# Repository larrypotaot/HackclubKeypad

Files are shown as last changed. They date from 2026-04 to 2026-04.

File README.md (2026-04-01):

# 60% Keyboard Addon For Gaming and Other
* A roughly 3x6 layout for F row and arrow keys, alongside a rotary encoder for fun. It is hotswappable and contains LEDs for each key
* I made this to have a dedicated F row and arrow keys for my 60% keyboard since many games require them and don't work with FN shortcuts.
* Uses QMK software
* *I need a soldering iron please :D



# PCB



Schematic


Layout: https://www.keyboard-layout-editor.com/#/gists/ed5083c6de0b27ba4e196096e7faea45

#BOM
* Solder Iron
* 3.5mm standoffs
* EVA foam

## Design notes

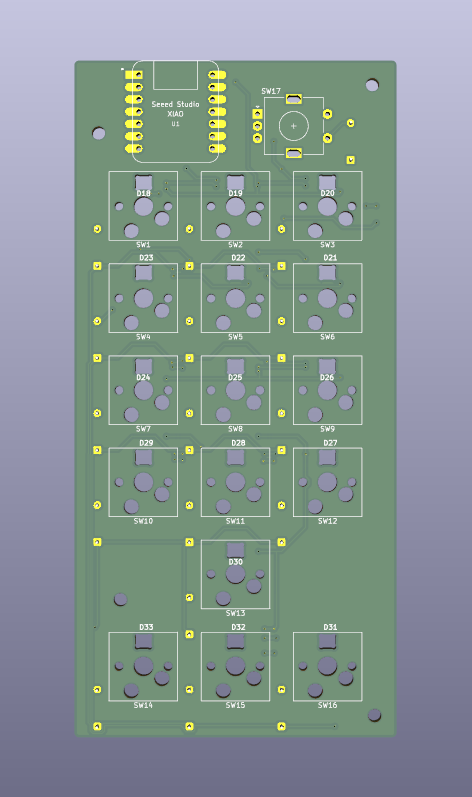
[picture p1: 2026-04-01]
images/PCBrender.png

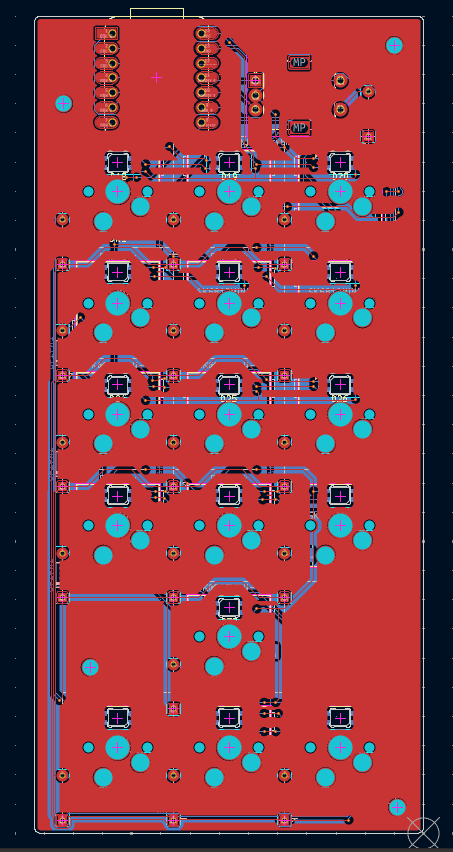
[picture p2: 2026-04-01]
images/PCBShematic.png

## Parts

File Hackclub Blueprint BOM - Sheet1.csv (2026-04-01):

Product Name | Product Link | Product Cost | Product Amount | Total Price
PCB from JCLPCB |  | $11.10 | 1 | $12.12
XIAO RP2040 MCU | https://www.aliexpress.us/item/3256808466485186.html?curPageLogUid=k8XzlSRWS6MQ | $4.87 | 1 | $12.81
EC11 Rotary Encoder | https://www.aliexpress.us/item/3256804721769785.html?curPageLogUid=tFcVPHu6YbhX | $3.33 | 1 | $2.18
Hotswap MX Socket | https://www.aliexpress.us/item/3256809607722645.html?curPageLogUid=7BINs2SNRA9A | $3.28 | 1 | $3.28
SK6812MINI-E LED | https://www.aliexpress.us/item/3256808122486614.html?curPageLogUid=gLfymRNrDhIw | $2.10 | 1 | $7.01
1N4148 Diodes |  | FREE |  | FREE
GATERON KS-3X1 V2 Milky Yellow Pro Switches | https://www.aliexpress.us/item/3256808499657735.html?curPageLogUid=gDV6XrdzS8fW | $12.19 | 1 | $12.19
Keycaps |  | FREE | 16 | FREE
M2.5 Screws and Nuts (8mm, 12mm, 16mm) |  | FREE |  | FREE

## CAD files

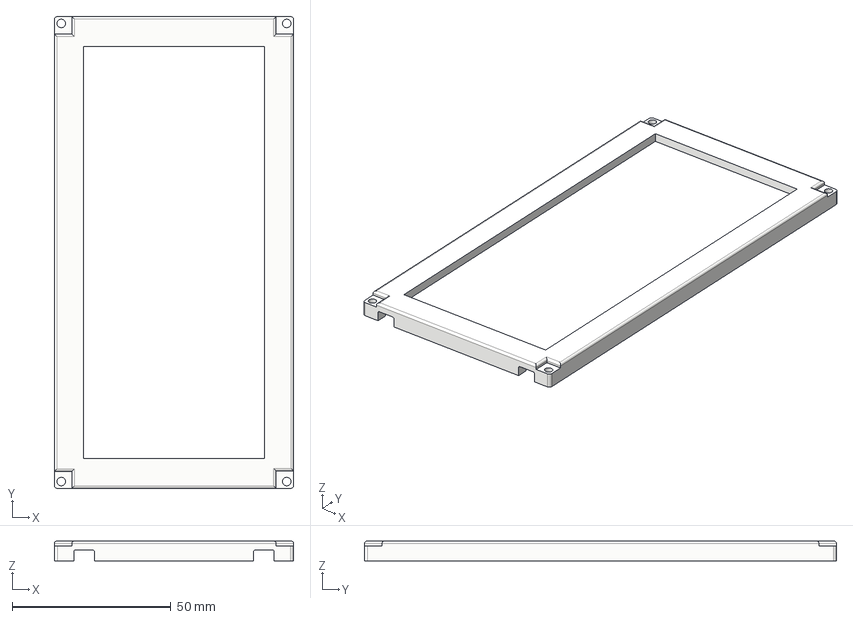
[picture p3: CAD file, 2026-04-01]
cad/TopCase.step
75.4 x 148.8 x 6.29 mm

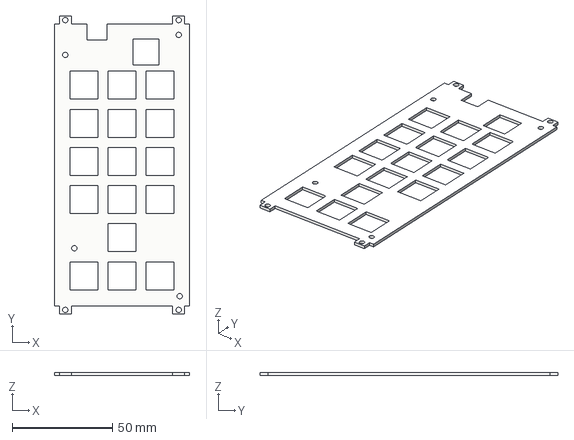
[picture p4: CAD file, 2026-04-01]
cad/Plate.step
67.5 x 148.8 x 1.50 mm

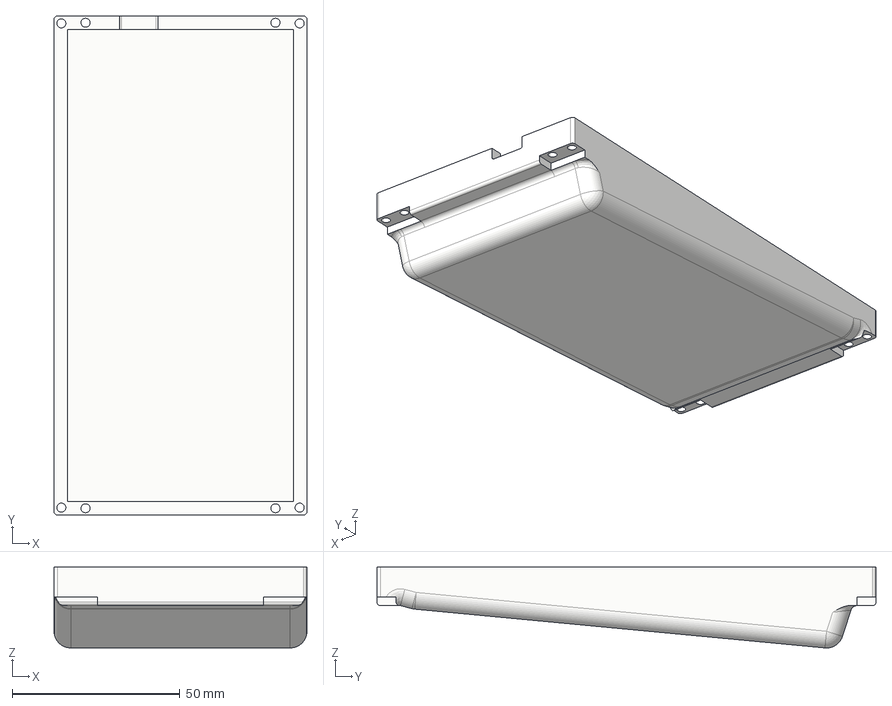
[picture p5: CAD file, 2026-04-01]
cad/BottomCase.step
75.5 x 148.8 x 24.1 mm

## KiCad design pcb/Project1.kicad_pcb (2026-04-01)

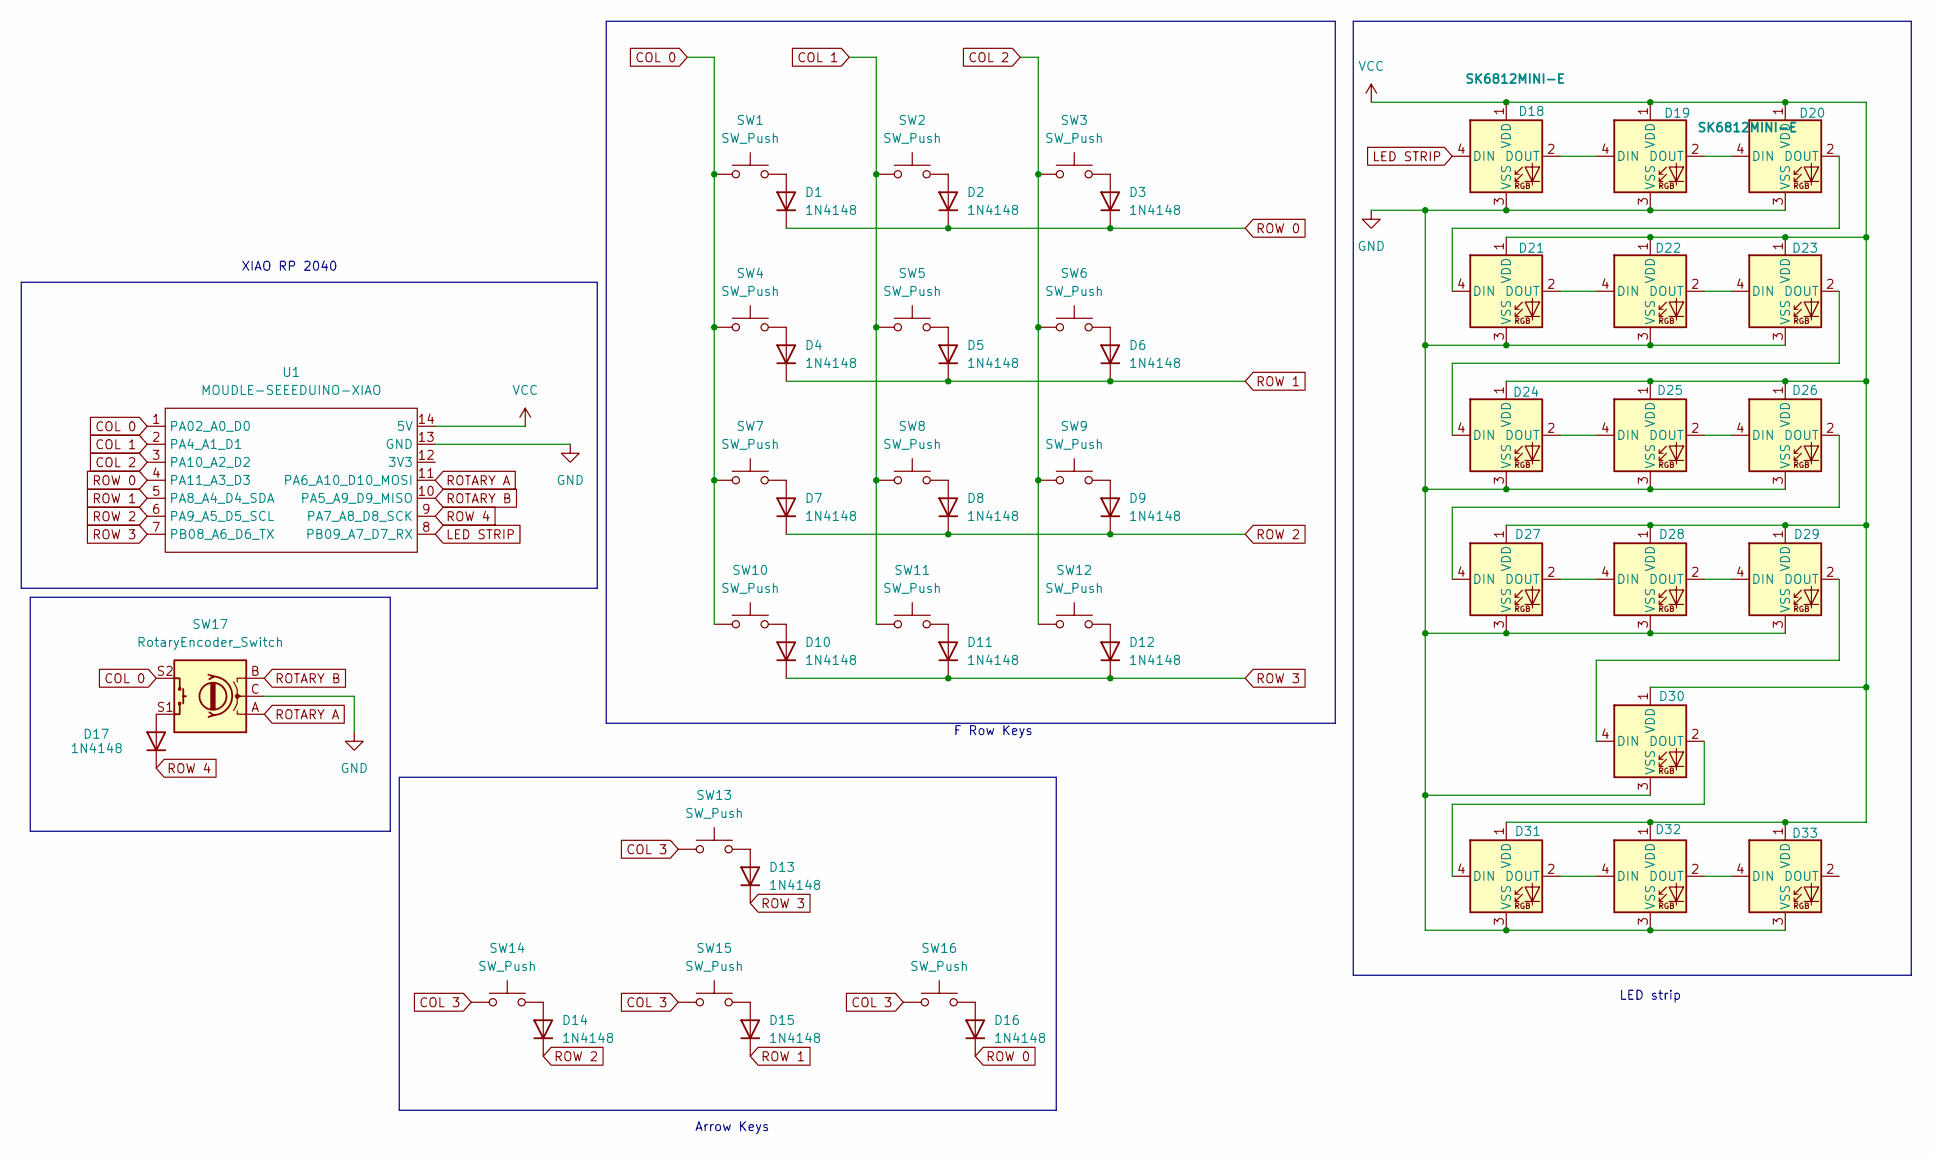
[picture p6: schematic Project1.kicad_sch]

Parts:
D1, D2, D3, D4, D5, D6, D7, D8, D9, D10, D11, D12, D13, D14, D15, D16, D17: 1N4148; D_DO-35_SOD27_P7.62mm_Horizontal
D18, D19, D20, D21, D22, D23, D24, D25, D26, D27, D28, D29, D30, D31, D32, D33: SK6812MINI-E; SK6812MINI-E_fixed
SW1, SW2, SW3, SW4, SW5, SW6, SW7, SW8, SW9, SW10, SW11, SW12, SW13, SW14, SW15, SW16: SW_Push; Hotswap_MX_1.00u
SW17: RotaryEncoder_Switch; RotaryEncoder_Alps_EC11E-Switch_Vertical_H20mm
U1: MOUDLE-SEEEDUINO-XIAO; XIAO-Generic-Hybrid-14P-2.54-21X17.8MM

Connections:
COL 0: SW1.1, SW4.1, SW7.1, SW10.1, SW17.S2, U1.1 (PA02_A0_D0)
COL 1: SW2.1, SW5.1, SW8.1, SW11.1, U1.2 (PA4_A1_D1)
COL 2: SW3.1, SW6.1, SW9.1, SW12.1, U1.3 (PA10_A2_D2)
COL 3: SW13.1, SW14.1, SW15.1, SW16.1
GND: D18.3 (VSS), D19.3 (VSS), D20.3 (VSS), D21.3 (VSS), D22.3 (VSS), D23.3 (VSS), D24.3 (VSS), D25.3 (VSS), D26.3 (VSS), D27.3 (VSS), D28.3 (VSS), D29.3 (VSS), D30.3 (VSS), D31.3 (VSS), D32.3 (VSS), D33.3 (VSS), SW17.C, U1.13 (GND)
LED STRIP: D18.4 (DIN), U1.8 (PB09_A7_D7_RX)
unnamed: D1.2 (A), SW1.2
unnamed: D2.2 (A), SW2.2
unnamed: D3.2 (A), SW3.2
unnamed: D4.2 (A), SW4.2
unnamed: D5.2 (A), SW5.2
unnamed: D6.2 (A), SW6.2
unnamed: D7.2 (A), SW7.2
unnamed: D8.2 (A), SW8.2
unnamed: D9.2 (A), SW9.2
unnamed: D10.2 (A), SW10.2
unnamed: D11.2 (A), SW11.2
unnamed: D12.2 (A), SW12.2
unnamed: D13.2 (A), SW13.2
unnamed: D14.2 (A), SW14.2
unnamed: D15.2 (A), SW15.2
unnamed: D16.2 (A), SW16.2
unnamed: D17.2 (A), SW17.S1
unnamed: D18.2 (DOUT), D19.4 (DIN)
unnamed: D19.2 (DOUT), D20.4 (DIN)
unnamed: D20.2 (DOUT), D21.4 (DIN)
unnamed: D21.2 (DOUT), D22.4 (DIN)
unnamed: D22.2 (DOUT), D23.4 (DIN)
unnamed: D23.2 (DOUT), D24.4 (DIN)
unnamed: D24.2 (DOUT), D25.4 (DIN)
unnamed: D25.2 (DOUT), D26.4 (DIN)
unnamed: D26.2 (DOUT), D27.4 (DIN)
unnamed: D27.2 (DOUT), D28.4 (DIN)
unnamed: D28.2 (DOUT), D29.4 (DIN)
unnamed: D29.2 (DOUT), D30.4 (DIN)
unnamed: D30.2 (DOUT), D31.4 (DIN)
unnamed: D31.2 (DOUT), D32.4 (DIN)
unnamed: D32.2 (DOUT), D33.4 (DIN)
ROTARY A: SW17.A, U1.11 (PA6_A10_D10_MOSI)
ROTARY B: SW17.B, U1.10 (PA5_A9_D9_MISO)
ROW 0: D1.1 (K), D2.1 (K), D3.1 (K), D16.1 (K), U1.4 (PA11_A3_D3)
ROW 1: D4.1 (K), D5.1 (K), D6.1 (K), D15.1 (K), U1.5 (PA8_A4_D4_SDA)
ROW 2: D7.1 (K), D8.1 (K), D9.1 (K), D14.1 (K), U1.6 (PA9_A5_D5_SCL)
ROW 3: D10.1 (K), D11.1 (K), D12.1 (K), D13.1 (K), U1.7 (PB08_A6_D6_TX)
ROW 4: D17.1 (K), U1.9 (PA7_A8_D8_SCK)
VCC: D18.1 (VDD), D19.1 (VDD), D20.1 (VDD), D21.1 (VDD), D22.1 (VDD), D23.1 (VDD), D24.1 (VDD), D25.1 (VDD), D26.1 (VDD), D27.1 (VDD), D28.1 (VDD), D29.1 (VDD), D30.1 (VDD), D31.1 (VDD), D32.1 (VDD), D33.1 (VDD), U1.14 (5V)

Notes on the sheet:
Arrow Keys
LED strip
F Row Keys
XIAO RP 2040

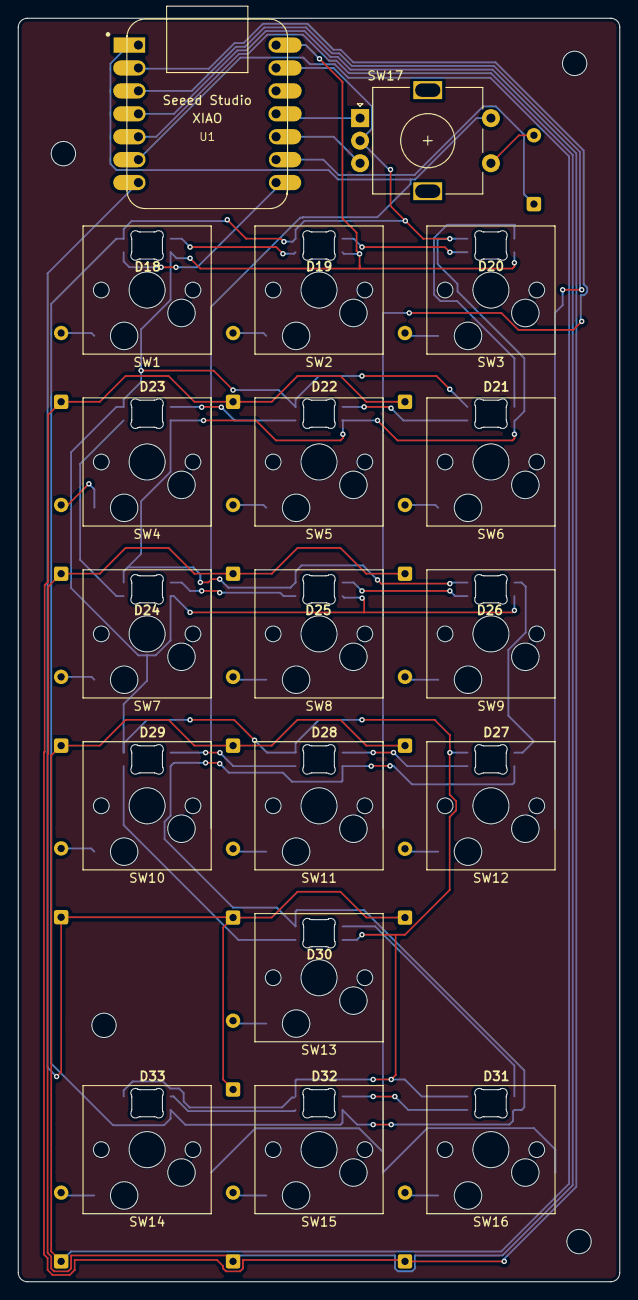
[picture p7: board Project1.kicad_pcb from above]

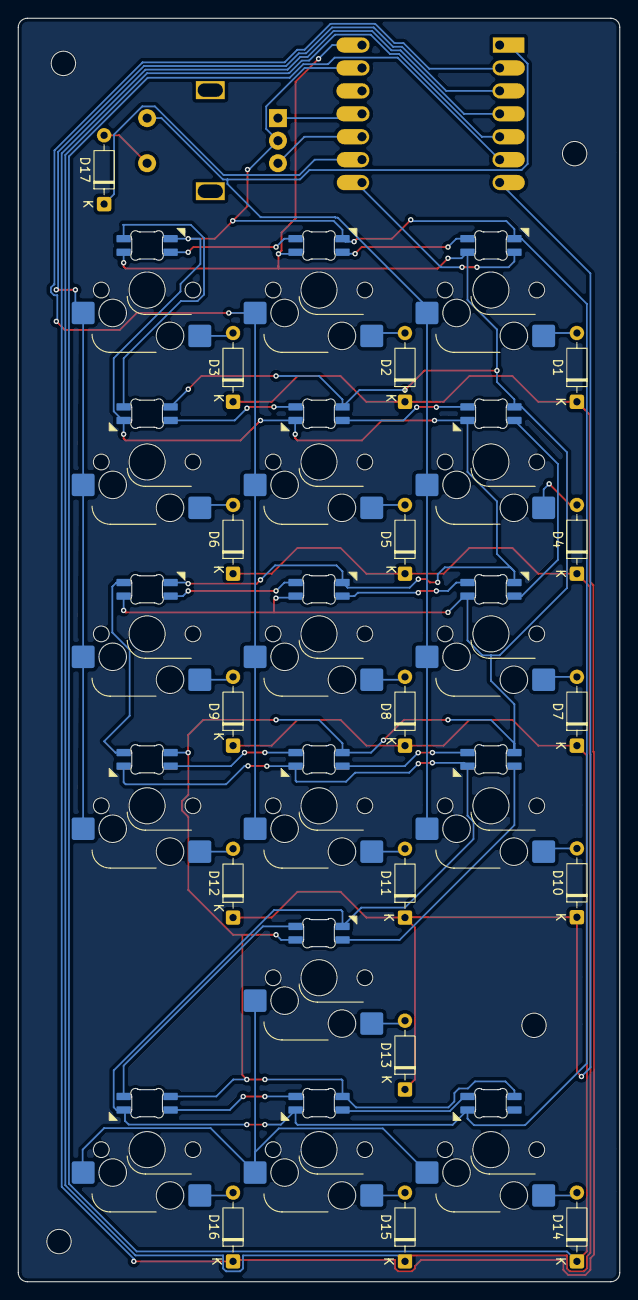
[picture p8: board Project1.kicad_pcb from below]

Board: 2 copper layers, 66.7 x 140.0 mm, 51 parts (17 on the bottom side), 46 nets.

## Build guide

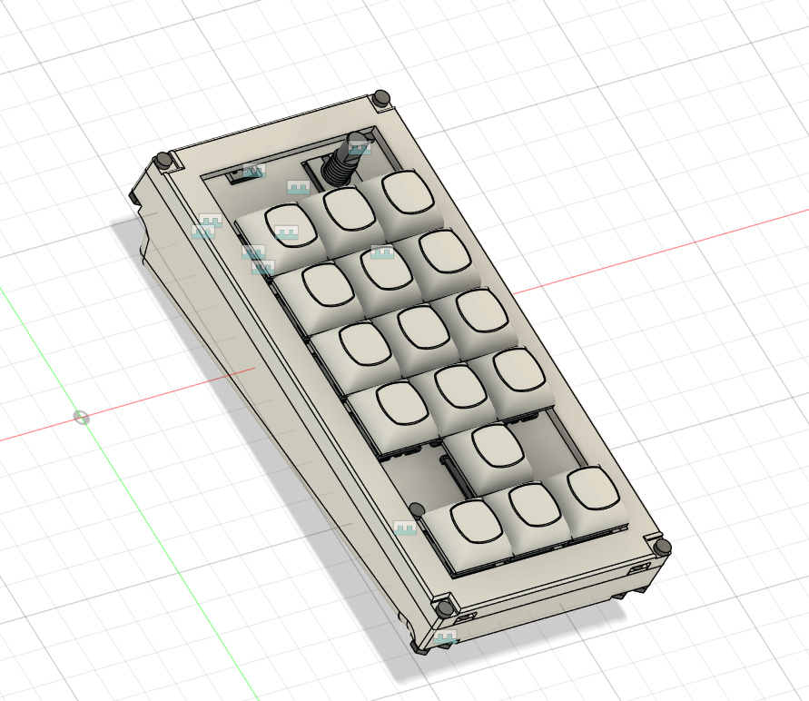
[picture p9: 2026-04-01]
images/CADassembly2.png

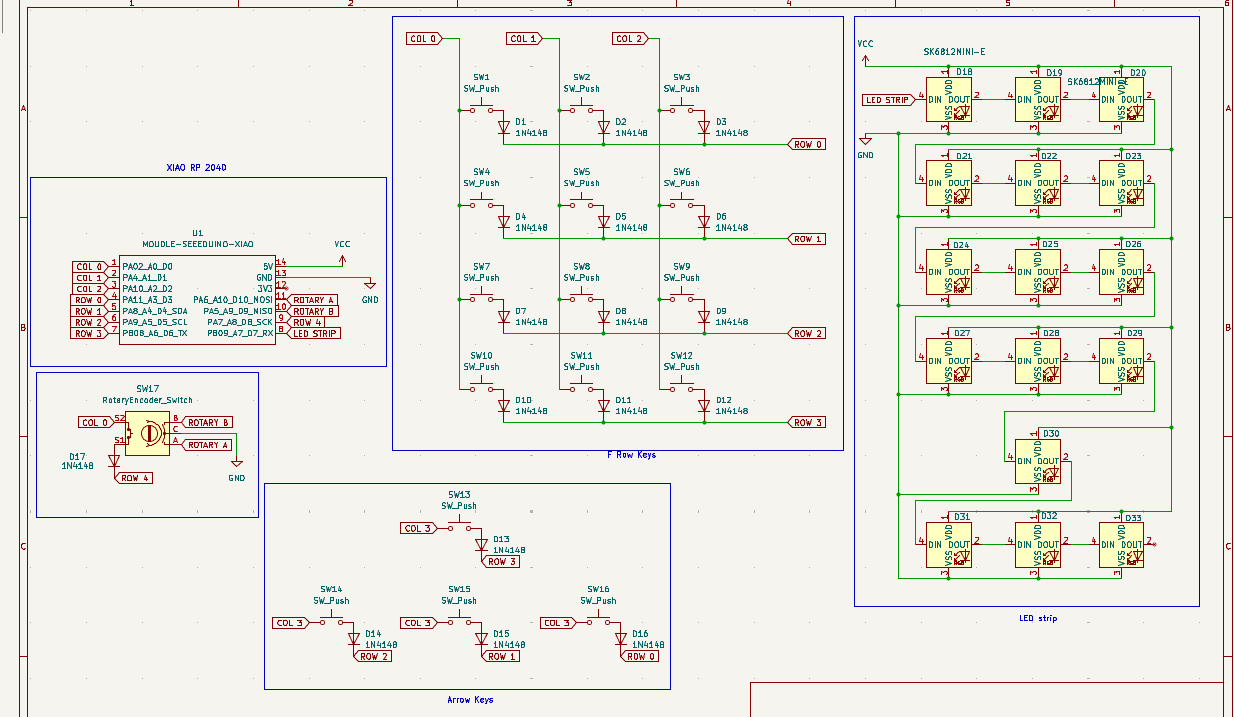
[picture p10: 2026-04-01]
images/WiringSchematic.png

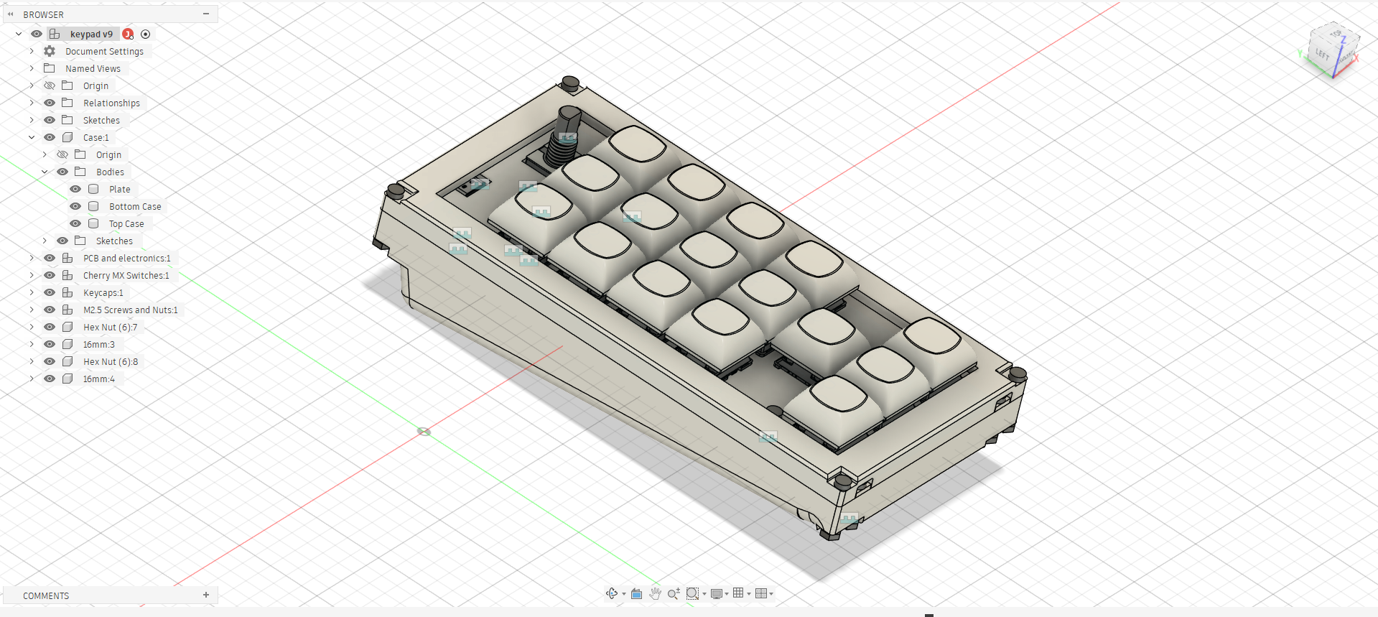
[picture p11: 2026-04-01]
images/CADassembly1.png
